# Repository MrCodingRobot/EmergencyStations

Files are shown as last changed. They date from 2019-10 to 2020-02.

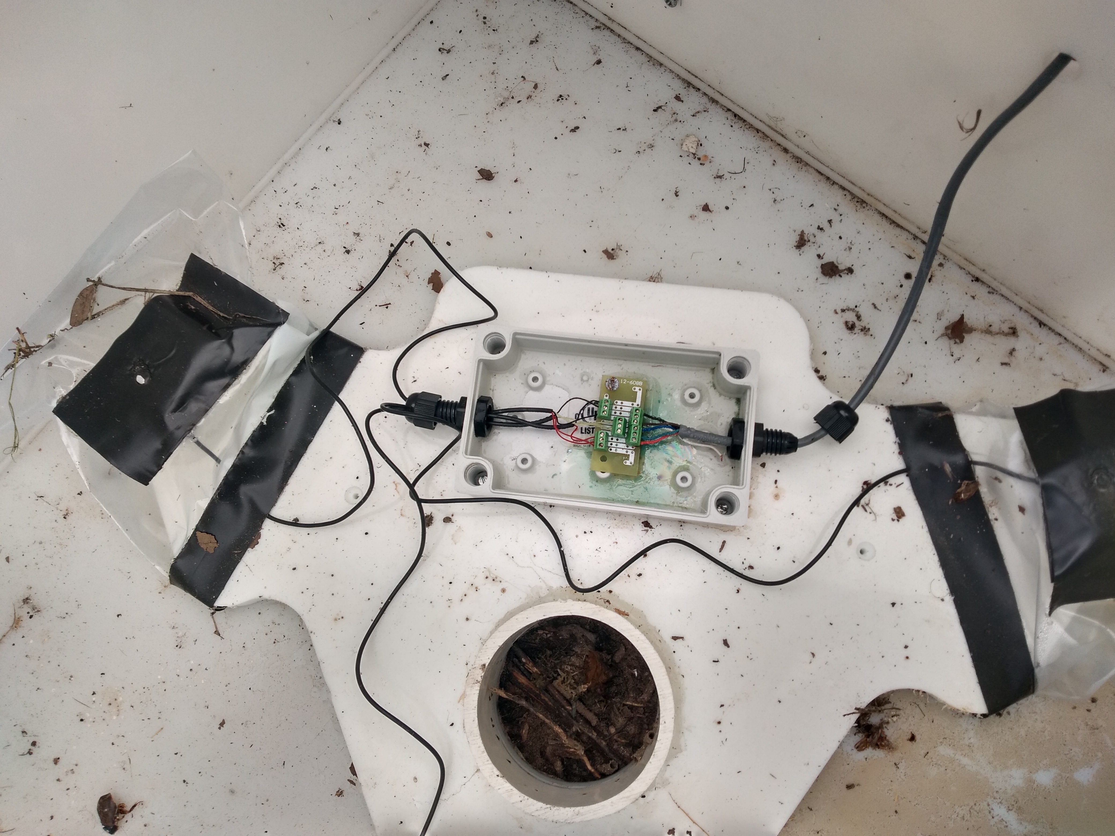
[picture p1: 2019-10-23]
Documentation/reports/trip_10_12_2019/image3.jpg

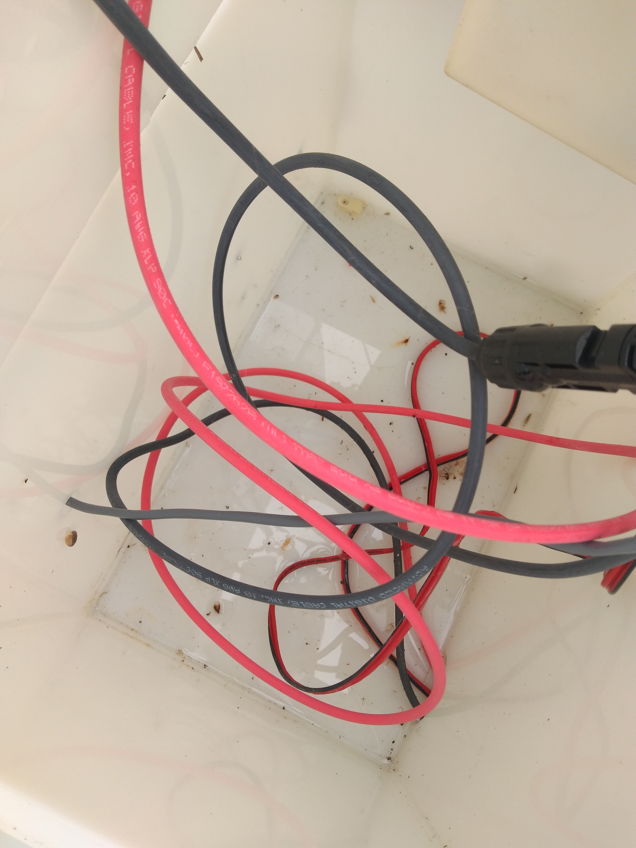
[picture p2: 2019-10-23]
Documentation/reports/trip_10_12_2019/image4.jpg

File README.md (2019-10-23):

# Emergency Stations

This project is the development of smart emergency stations. This
stations reports, via cellular data, vital inventory information that
can assist the maintance of a large collection of emergency stations.
This helps ensure that all emergency stations are stocked sufficiently
and efficiently to assure that people in need actually have supplies
when an emergency occurs.

Within this repository, the hardware, software, and additional
documentation regarding the projects development are collected.
The goal of this repository is to ensure that development progress
into this project is documentated, to make the continuation of this
project possible.

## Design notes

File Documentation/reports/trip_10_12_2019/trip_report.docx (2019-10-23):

October 12, 2019 Trip Report

Farzan A., Mehran A., Eduardo D., David (Ethan) D.

Purpose

- Implement hardware and software changes into all of the 5 phase 1 water stations.
  - Hardware
    - Placed 4x4 blocks underneath the stations to elevate the stations, making water accumulation less probable.
    - Drilled drain holes in all compartments.
    - Removed water-proof tarps (due to accumulation of bugs/snakes).
    - Improved lids for electrical boxes.
    - Implemented better water-proof connectors between weight sensors and the electrical box.
    - Implemented better weight sensor covers, from plastic bags to 3D-printed tight seals.
  - Software
    - Improved arduino and network control software.
    - Implemented station-dependent calibration to improve weight calculation.

Past Error Observations

- Phase 2 Station 6 case broke in center point due to weight. Trashed.
- Previous box connectors between weight sensors and electrical box were flooded. This can be seen in the images within the current working directory of this file. This explains why station 5 (confirmed) was not reporting correct values.
- Water accumulation in all compartment was true. This is due to a lack of drain holes.
  - Electrical boxes were compromised due to weak water seal in lids
  - Weight sensors were wet.

Problems Encountered

- Station 3 had different electrical configuration within the electrical box
  - Arduino in station 3 was powered from battery instead of solar charger.
- One of the weight sensors from station 5 was faulty, had to replace it by salvaging a sensor from broken phase 2 station 6 weight sensors. They are the same type of sensors, with the same max weight value (100 lbs).

Post-Trip Tasks

- Normalize station 3 electrical box to conform with the other electrical boxes .
- Monitor the operation of all the stations to ensure that they are working.

Post-Trip Failures

- Station 4 is not transmitting any information, need to help troubleshoot this station.
- Website is not updating google maps markers

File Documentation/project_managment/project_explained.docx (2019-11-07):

EMERGENCY STATIONS

PROJECT EXPLAINED

Version 1

Date: 11/6/2019

Document’s Purpose: To explain the innerworkings of the project to achieve the project’s vision. This is an extensive document elaborating the software and hardware of the project.

MECHANICAL HARDWARE

***

This section needs some work and the CAD files for the mechanical hardware is missing!

***

ELECTRICAL HARDWARE

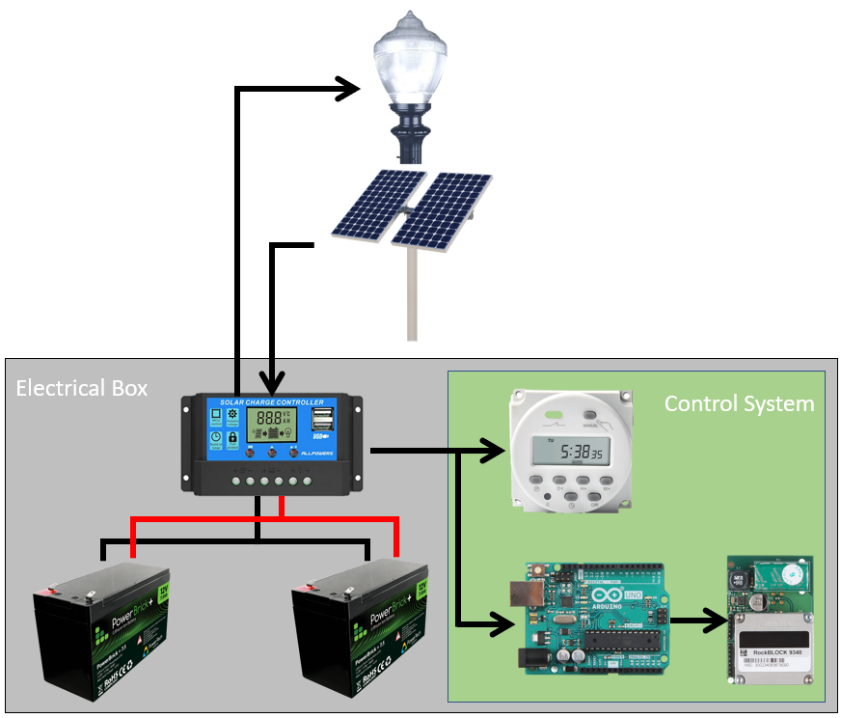
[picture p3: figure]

Figure 2.1: Electrical Hardware Diagram

This section deals with the electrical hardware of the system, consisting of the solar panels, solar charger controller, rechargeable 12V Lithium batteries, and the control system. The control system is composed of digital clock switch for the pole’s light, a microcontroller (Arduino) and the communication module (RockBLOCK).

The power obtained from the solar panel is processed and handle by the solar charger controller to properly charge the 12V batteries. Then the solar charger controller has a USB port that is used to run the Arduino and the RockBLOCK. Whenever the solar panel is not outputting enough voltage to power the solar charger, the voltage of the batteries ensure that the solar charger controller is powered and supplying power to the control systems.

SOFTWARE

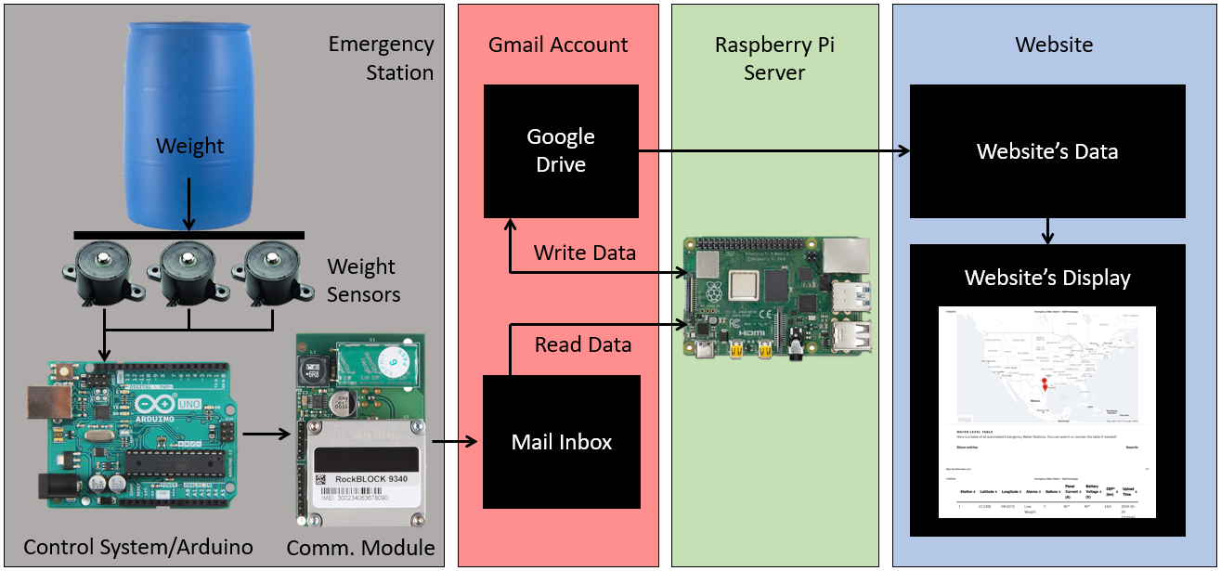
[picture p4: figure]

Figure 3.1: Software Subsystem Diagram

The software subsystem of the project is composed of two main components: the emergency station software within the Arduino, and the Raspberry Pi Server. The weight within a barrel is recorded by three weight sensors. The weight values are summed and converted to a value in pounds (lbs.). Weight values are recorded every 90 minutes for a total of eight times. One cycle of data collection is 12 hours. Afterwards, these values are transmitted by the Communication Module (RockBLOCK) that is connected to the Arduino.

When the Communication Module transmits data, it is sent as an email where the subject contains the GPS location of the module and the weight data recorded by the Arduino. The Raspberry Pi Server is routinely checking for new emails from the ESs. If a new email is detected, the weight data within the new email is read, recorded, and saved to a master excel file within the gmail’s google drive. Additionally, the Raspberry Pi generates other excel files that update the GPS locations within the Google Maps plugin and the most up to date ESs’ inventory values within a Table plugin. These plugins are supplied by WordPress, which is the platform used to operate the website.

The latest 100 points from the data points of the ES is used to plot the changing weight and sensor values. This helps diagnose and troubleshoot possible problems for individual ES.

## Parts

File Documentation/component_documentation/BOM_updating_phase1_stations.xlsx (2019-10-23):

Quantity | Part | Tools Needed
4 | Water Station Lid | Drill
12 | Force Sensor Cover | 1in drill bit
16 | 3/8x2.5in lag screws and washers | 3/8in drill bit
8 | 2ft 4x4 boards | 1/4in drill bit
4 | 6-pin waterproof connectors | soldering iron
1 | heat shrink tubing | socket wrench (7/16in or 1/2in)
1 | gorillaz table

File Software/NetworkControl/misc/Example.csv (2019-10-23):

id | map_id | address | description | pic | link | lat | lng | icon | anim | title | infoopen | category | approved | retina | type | did | other_data
6435 | 81 | 39.90498,116.427217 |  |  |  | 39.90498 | 116.427217 |  | 0 | Beijing Railway Station | 0 | 0 | 1 | 0 | 0
6436 | 81 | 39.894834,116.32111 |  |  |  | 39.894834 | 116.32111 |  | 0 | Beijing West | 0 | 0 | 1 | 0 | 0
6437 | 81 | 32.086727,118.796834 |  |  |  | 32.086727 | 118.796834 |  | 0 | Nanjing Railway Station | 0 | 0 | 1 | 0 | 0
6438 | 81 | 31.2508246,121.4506144 |  |  |  | 31.250825 | 121.450614 |  | 0 | Shanghai Railway Station | 0 | 0 | 1 | 0 | 0
6439 | 81 | 24.636169,118.074064 |  |  |  | 24.636169 | 118.074064 |  | 0 | Xiamen North Railway Station | 0 | 0 | 1 | 0 | 0
6440 | 81 | 22.989053,113.269698 |  |  |  | 22.989053 | 113.269698 |  | 0 | Guangzhou South | 0 | 0 | 1 | 0 | 0
6441 | 81 | 30.6311561,104.1390591 |  |  |  | 30.631156 | 104.139059 |  | 0 | &#x6210;&#x90FD;&#x4E1C; | 0 | 0 | 1 | 0 | 0 |  | a:1:{i:0;s:1:"0";}
6442 | 81 | 28.146783,113.06508 |  |  |  | 28.146783 | 113.06508 |  | 0 | &#x957F;&#x6C99;&#x5357; | 0 | 0 | 1 | 0 | 0 |  | a:1:{i:0;s:1:"0";}
6443 | 81 | 30.696822,104.073374 |  |  |  | 30.696822 | 104.073374 |  | 0 | Chengdu Railway Station | 0 | 0 | 1 | 0 | 0
6444 | 81 | 29.549747,106.547669 |  |  |  | 29.549747 | 106.547669 |  | 0 | Chongqing Railway Station | 0 | 0 | 1 | 0 | 0

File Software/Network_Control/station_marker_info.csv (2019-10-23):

id | map_id | address | description | pic | link | lat | lng | icon | anim | title | infoopen | category | approved | retina | type | did | other_data
1 | 81 | 29.4434,-98.5267 |  |  |  | 29.4434 | -98.5267 |  | 0 | Station 1 | 0 | 0 | 1 | 0 | 0
24 | 81 | 27.2013,-98.1072 |  |  |  | 27.2013 | -98.1072 |  | 0 | Stations 2, and 4 | 0 | 0 | 1 | 0 | 0
3 | 81 | 27.2334,-98.1072 |  |  |  | 27.2334 | -98.1072 |  | 0 | Station 3 | 0 | 0 | 1 | 0 | 0
5 | 81 | 27.1990,-98.1472 |  |  |  | 27.1990 | -98.1472 |  | 0 | Station 5 | 0 | 0 | 1 | 0 | 0
6 | 81 | 27.0354,-98.1757 |  |  |  | 27.0354 | -98.1757 |  | 0 | Station 6 | 0 | 0 | 1 | 0 | 0

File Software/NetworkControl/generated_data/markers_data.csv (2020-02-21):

id | map_id | address | description | pic | link | lat | lng | icon | anim | title | infoopen | category | approved | retina | type | did | other_data
1 | 81 | 26.9893, -98.1301 |  |  |  | 26.9893 | -98.1301 |  | 0 | Station 1 | 0 | 0 | 1 | 0 | 0
2 | 81 | 26.5789, -99.0332 |  |  |  | 26.5789 | -99.0332 |  | 0 | Station 2 | 0 | 0 | 1 | 0 | 0
3 | 81 | 27.2311, -98.1472 |  |  |  | 27.2311 | -98.1472 |  | 0 | Station 3 | 0 | 0 | 1 | 0 | 0
4 | 81 | 27.199, -98.1472 |  |  |  | 27.199 | -98.1472 |  | 0 | Station 4 | 0 | 0 | 1 | 0 | 0
5 | 81 | 26.987, -98.17 |  |  |  | 26.987 | -98.17 |  | 0 | Station 5 | 0 | 0 | 1 | 0 | 0

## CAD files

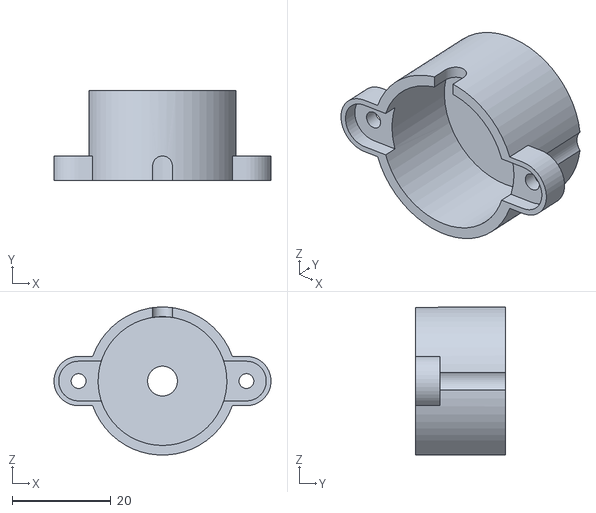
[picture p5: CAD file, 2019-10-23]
Hardware/force sensor cover.STL
44.0 x 18.3 x 30.0

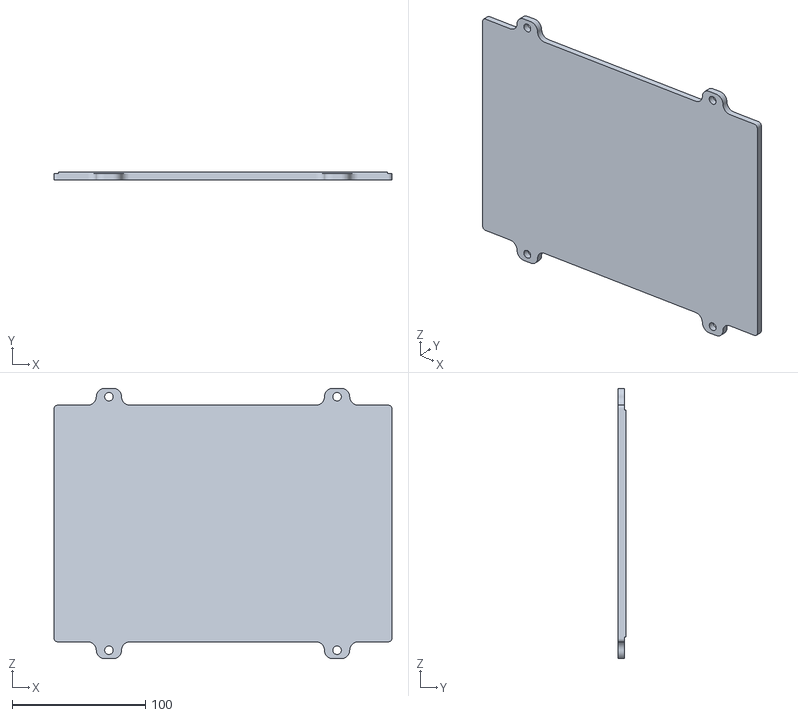
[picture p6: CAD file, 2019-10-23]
Hardware/water station lid.STL
254.0 x 6.03 x 203.2

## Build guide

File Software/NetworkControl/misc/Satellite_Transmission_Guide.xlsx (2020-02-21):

 | Stored Data
Index | Phase 1 | Phase 2
0 | Station # | Station #
1 | Alarm | Alarm
2 | Sensor1 1 | Weight 1
3 | Sensor2 1 | Current 1
4 | Sensor3 1 | Voltage 1
5 | Reference 1 | Weight 2
6 | Weight 1 | Current 2
7 | Sensor1 2 | Voltage 2
8 | Sensor2 2 | Weight 3
9 | Sensor3 2 | Current 3
10 | Reference 2 | Voltage 3
11 | Weight 2 | Weight 4
12 | Sensor1 3 | Current 4
13 | Sensor2 3 | Voltage 4
14 | Sensor3 3 | Weight 5
15 | Reference 3 | Current 5
16 | Weight 3 | Voltage 5
17 | Sensor1 4 | Weight 6
18 | Sensor2 4 | Current 6
19 | Sensor3 4 | Voltage 6
20 | Reference 4 | Weight 7
21 | Weight 4 | Current 7
22 | Sensor1 5 | Voltage 7
23 | Sensor2 5 | Weight 8
24 | Sensor3 5 | Current 8
25 | Reference 5 | Voltage 8
26 | Weight 5 | Weight 9
27 | Sensor1 6 | Current 9
28 | Sensor2 6 | Voltage 9
29 | Sensor3 6 | Weight 10
30 | Reference 6 | Current 10
31 | Weight 6 | Voltage 10
32 | Sensor1 7 | Weight 11
33 | Sensor2 7 | Current 11
34 | Sensor3 7 | Voltage 11
35 | Reference 7 | Weight 12
36 | Weight 7 | Current 12
37 | Sensor1 8 | Voltage 12
38 | Sensor2 8 | Weight 13
39 | Sensor3 8 | Current 13
40 | Reference 8 | Voltage 13
41 | Weight 8 | Weight 14
42 | EMPTY | Current 14
43 | EMPTY | Voltage 14
44 | EMPTY | Current Index*
45 | Present Weight | Present Weight
46 | EMPTY | Present Current
47 | EMPTY | Present Voltage
 |  | *Current Index is the index where the current readings (besides the "present" readings) are held.
 |  | Readings from the past 12 hours are interpretted by reading the values at the current index and
 |  | working backwards, wrapping around as needed.

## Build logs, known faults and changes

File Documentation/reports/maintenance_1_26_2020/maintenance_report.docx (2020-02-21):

Maintenance Report

01/26/2020 – 8:20 PM

Eduardo D.

Note: The original larger-size higher-quality JPGs of the stations’ historical data is available within this file’s current working directory.

Station 1 (Phase 1) - 300234067638620@rockblock.rock7.com

Status: Deployed, Idle (Non-functioning properly)

Last Email Received Datetime: 01/08/2020 – 10:31 PM (Website values agree)

Last Weight Value: 6 gallons

Historical Data:

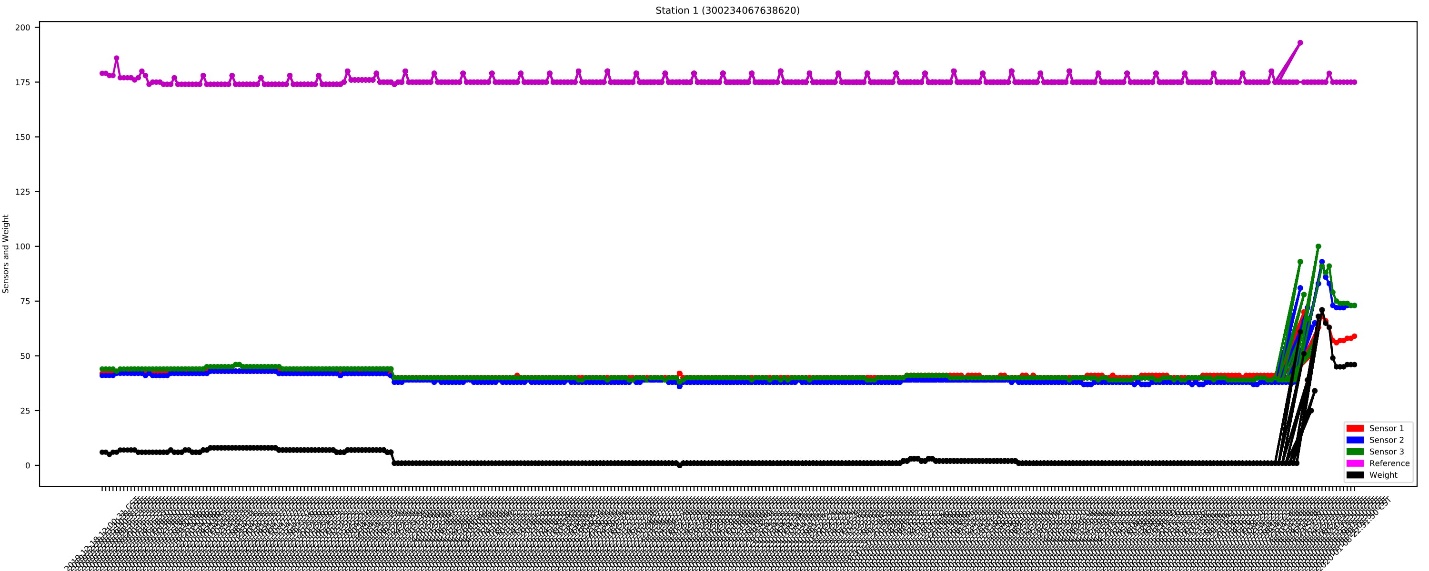
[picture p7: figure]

Diagnosis:

The high concentration of data points at the end of this plot implies that a reset was attempted. The reset is recognized to have occurred on late 1/07/2020. After the reset, there is a small amount of stability for the sensor and weight values, implying that the station was functional after the reset. However, this station has stopped transmitting the information. The most likely cause of this discontinued of service can be the following (of decreasing likeability:

- Software Fault after automatic reset (the case was not tested during development)
- Wiring Disconnection during water station deployment
- Faulty redeployment
- RockBLOCK communication failure
- Arduino Long Operation failure (memory issues ?)

Station 2 (Phase 1) - 300234067639570@rockblock.rock7.com

Status: Deployed, Idle (Non-functioning properly)

Last Email Received Datetime: 01/08/2020 – 7:58 PM (Website values agree)

Last Weight Value: 12 gallons

Historical Data:

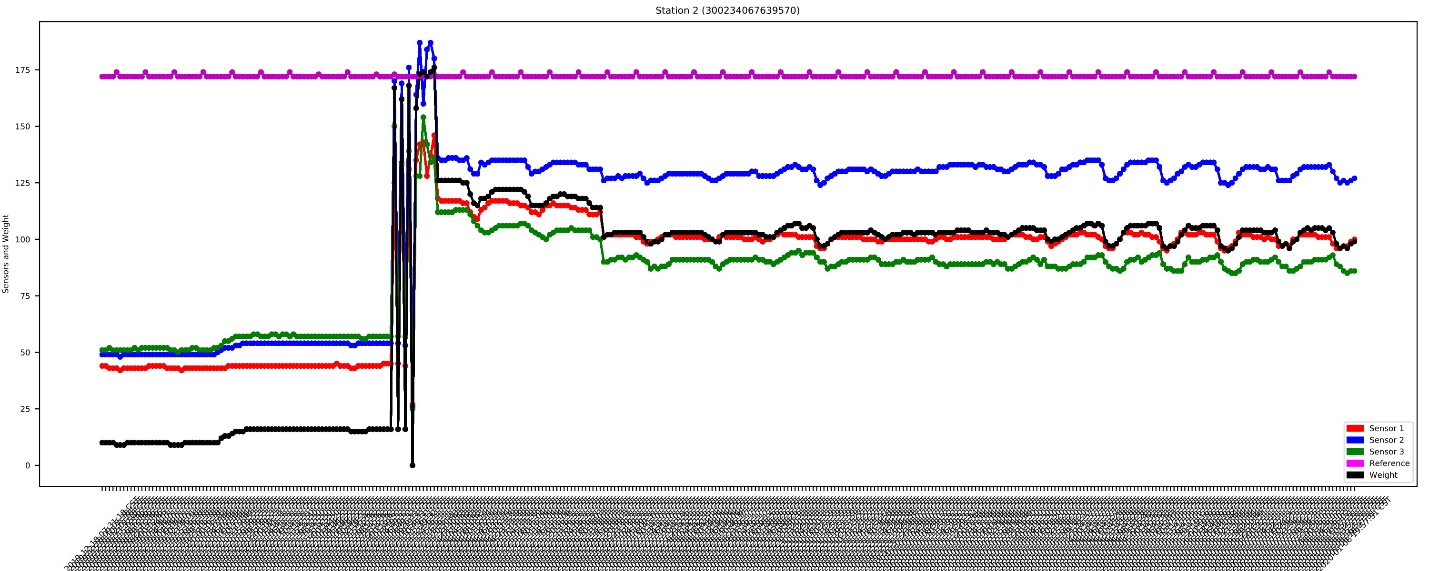
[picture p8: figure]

Diagnosis:

This station was deployed on 12/23/2019 (based on what our data says, not what the user says), which is then placed where the graph spikes up in value. This is mostly due to the changing value of the weight sensors during setup. Then the station stagnates for a period of time, mostly at around 100 lbs (≈12 gallons) for the weight. This agrees with the most up-to-date value in the southtexashrc.com website, it reported 12 gallons. This water station is much more difficult to diagnosis as the station just suddenly stopped transmitting the information. The fact that it stopped transmitting information the same day Station 1 failed implies that an external force is the cause of the problem.

Station 3 (Phase 1) - 300234067431270@rockblock.rock7.com

Status: Unknown, Idle (Unknown – Possibly not powered)

Last Email Received Datetime: 09/12/20219 – 7:29 PM

Last Weight Value: 2 gallons (Website values agree)

Historical Data:

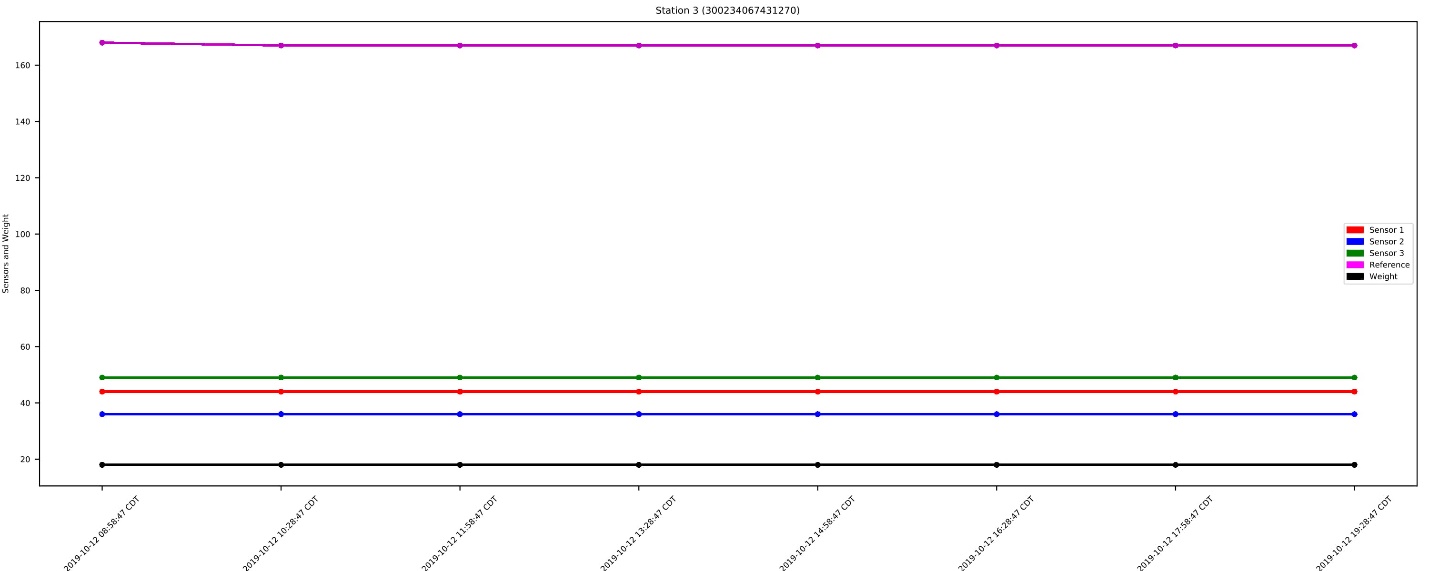
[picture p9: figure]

Diagnosis:

The trip to change Phase 1 stations occurred on October 12, 2019. During this trip, we realized that station 3 had a different electrical layout where the Arduino microcontroller was connected to the batteries through its 9V input port instead of being connected to the solar charger via a USB connector. We tried to make this station conform with the other water stations' circuit layout. However, we realized that the USB port of the solar charger in station 3 was faulty and could not be used. The electrical box was returned to on-site personnel. We are waiting for them to place the electrical box to its designated compartment and initiate the station's service.

Station 4 (Phase 1) - 300234067638500@rockblock.rock7.com

Status: Unknown, Idle (Definitely Non-functioning properly)

Last Email Received Datetime: 09/12/2019 – 6:53 PM

Last Weight Value: 3 gallons (Website values agree)

Historical Data:

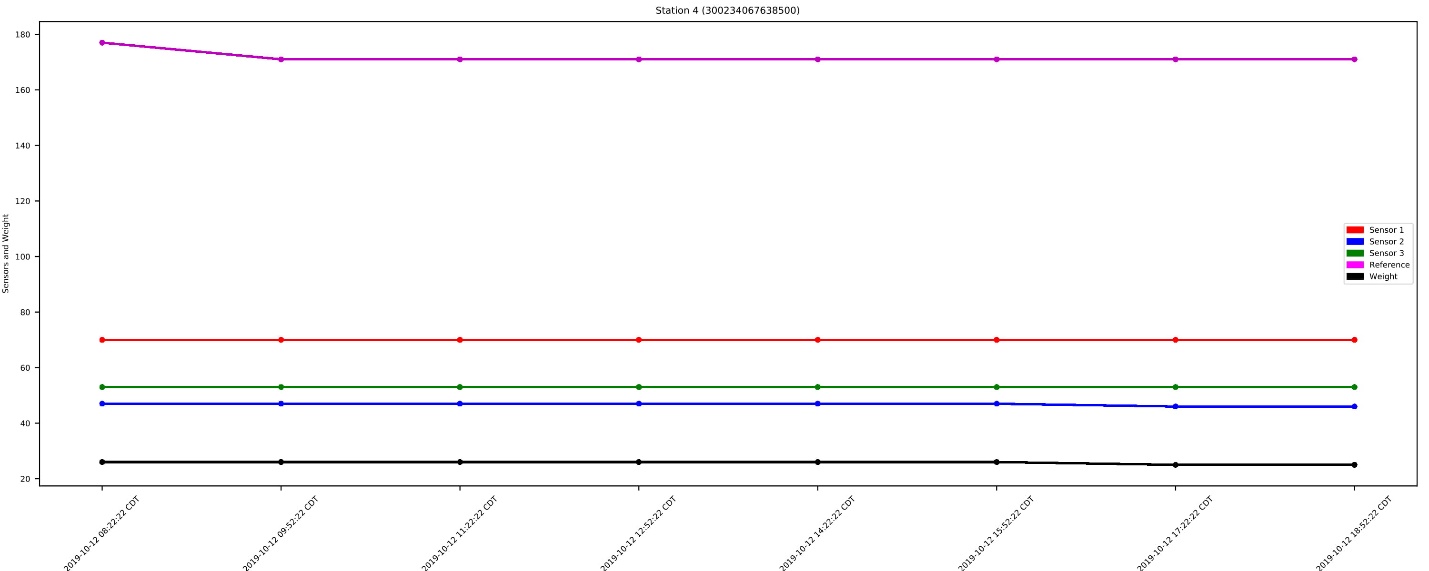
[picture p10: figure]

Diagnosis:

During the 09/12/19 trip, station 4 was modified, calibrated, setup, and confirm to have transmitted its first email. Once the engineering team returned to San Antonio, station 4 stopped transmitting the information. The cause remains unknown. We have not received any additional information regarding the station; therefore, communication with on-site personnel is needed to properly diagnose.

Possible Causes:

- Faulty Setup
- Faulty Calibration
- ???

Station 5 (Phase 1) - 300234067638200@rockblock.rock7.com

Status: Deployed, Idle (Non-functioning properly)

Last Email Received Datetime: 01/08/2020 – 5:02 PM

Last Weight Value: 6 gallons (Website values agree)

Historical Data:

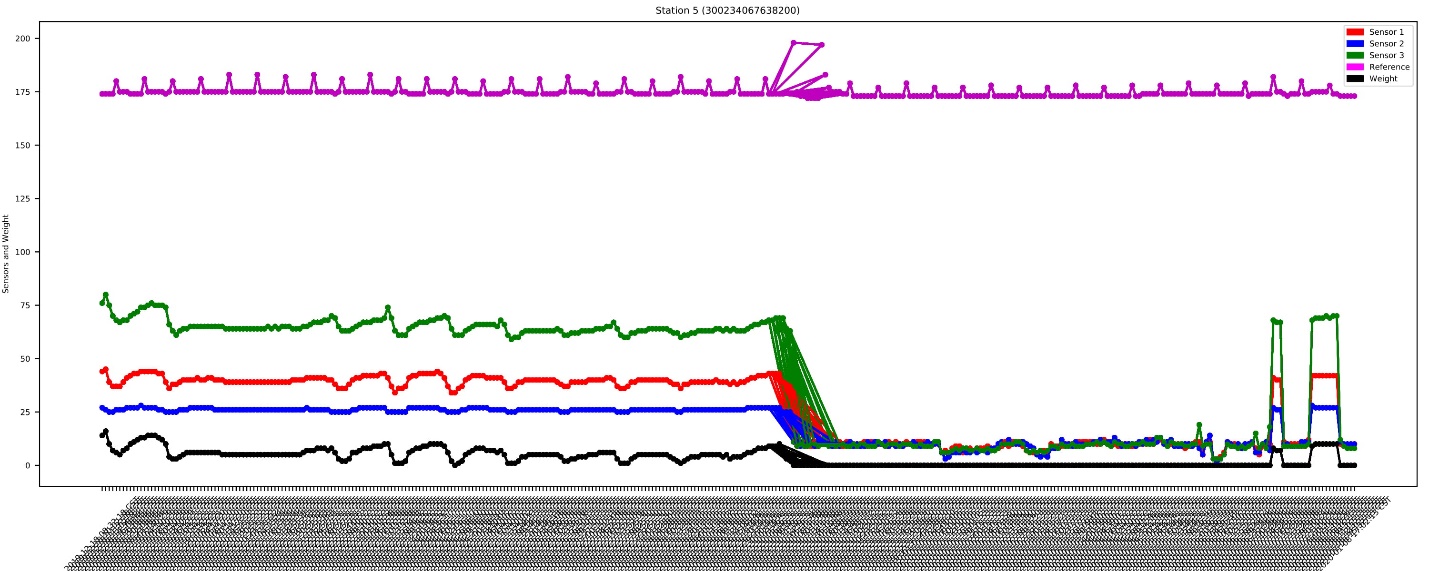
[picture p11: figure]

Diagnosis:

When the weight of the station is 0, or just very low, it implies that the barrel was removed. We can see in the far right of the plot that the barrel was repetitively removed and replaced. The transmission of data ended on 01/08/2020, which is also the same time as stations 1 and 2 failed, implying that the problem is linked together and related to a shared external force.

Station 6 (Phase 2) - 300234067929930@rockblock.rock7.com

Status: Dead

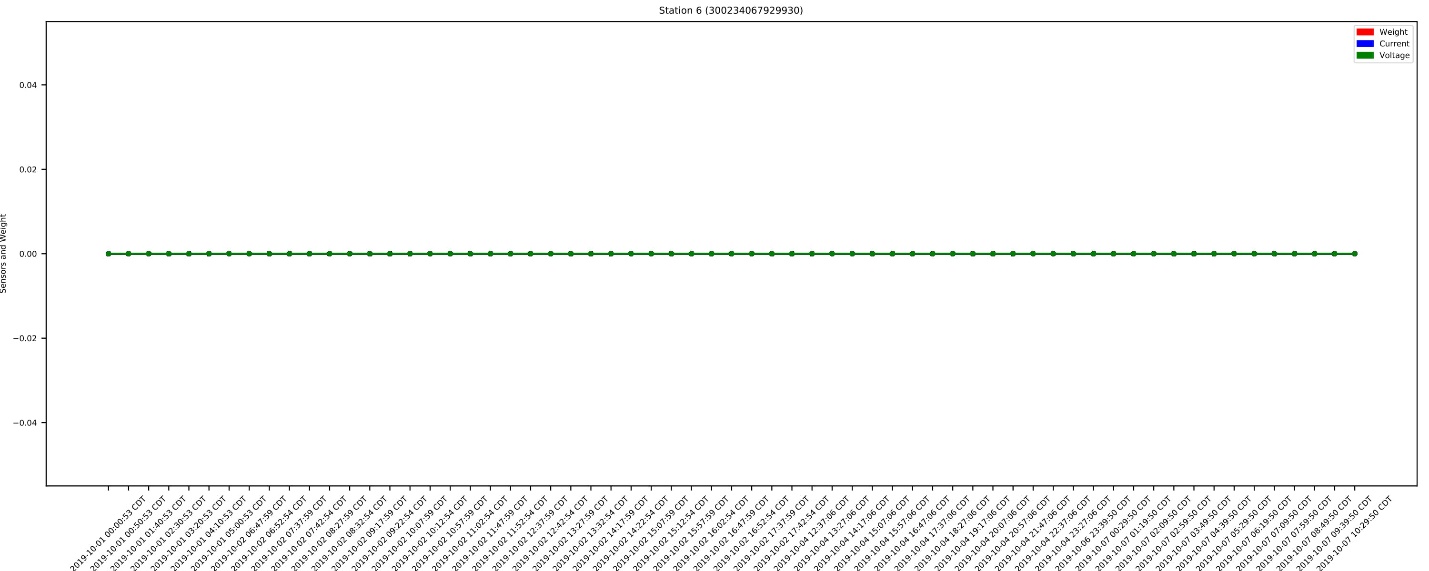
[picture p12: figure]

Diagnosis:

Discontinued station – the station was broken and tossed in the trash.

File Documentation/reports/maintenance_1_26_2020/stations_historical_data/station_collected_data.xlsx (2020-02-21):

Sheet: Station 1 (300234067638620)
Time | Sensor 1 | Sensor 2 | Sensor 3 | Reference | Weight
2019-11-15 01:08:10 CST | 43 | 42 | 44 | 183 | 7
2019-11-15 02:38:10 CST | 43 | 42 | 44 | 177 | 7
2019-11-15 04:08:10 CST | 43 | 42 | 44 | 177 | 7
2019-11-15 05:38:10 CST | 43 | 42 | 44 | 177 | 7
2019-11-15 07:08:10 CST | 43 | 42 | 44 | 177 | 7
2019-11-15 08:38:10 CST | 43 | 42 | 44 | 177 | 7
2019-11-15 10:08:10 CST | 42 | 42 | 44 | 177 | 6
2019-11-15 11:38:10 CST | 43 | 42 | 43 | 176 | 6
2019-11-15 13:12:18 CST | 43 | 41 | 44 | 182 | 6
2019-11-15 14:42:18 CST | 42 | 41 | 44 | 176 | 6
2019-11-15 16:12:18 CST | 43 | 42 | 44 | 176 | 7
2019-11-15 17:42:18 CST | 43 | 42 | 44 | 177 | 7
2019-11-15 19:12:18 CST | 43 | 42 | 44 | 177 | 7
2019-11-15 20:42:18 CST | 43 | 42 | 44 | 177 | 7
2019-11-15 22:12:18 CST | 43 | 42 | 44 | 177 | 7
2019-11-15 23:42:18 CST | 43 | 42 | 44 | 177 | 7
2019-11-16 01:15:27 CST | 43 | 42 | 44 | 182 | 7
2019-11-16 02:45:27 CST | 43 | 42 | 44 | 177 | 7
2019-11-16 04:15:27 CST | 43 | 42 | 44 | 177 | 7
2019-11-16 05:45:27 CST | 43 | 42 | 44 | 177 | 7
2019-11-16 07:15:27 CST | 42 | 42 | 44 | 177 | 6
2019-11-16 08:45:27 CST | 42 | 42 | 44 | 177 | 6
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

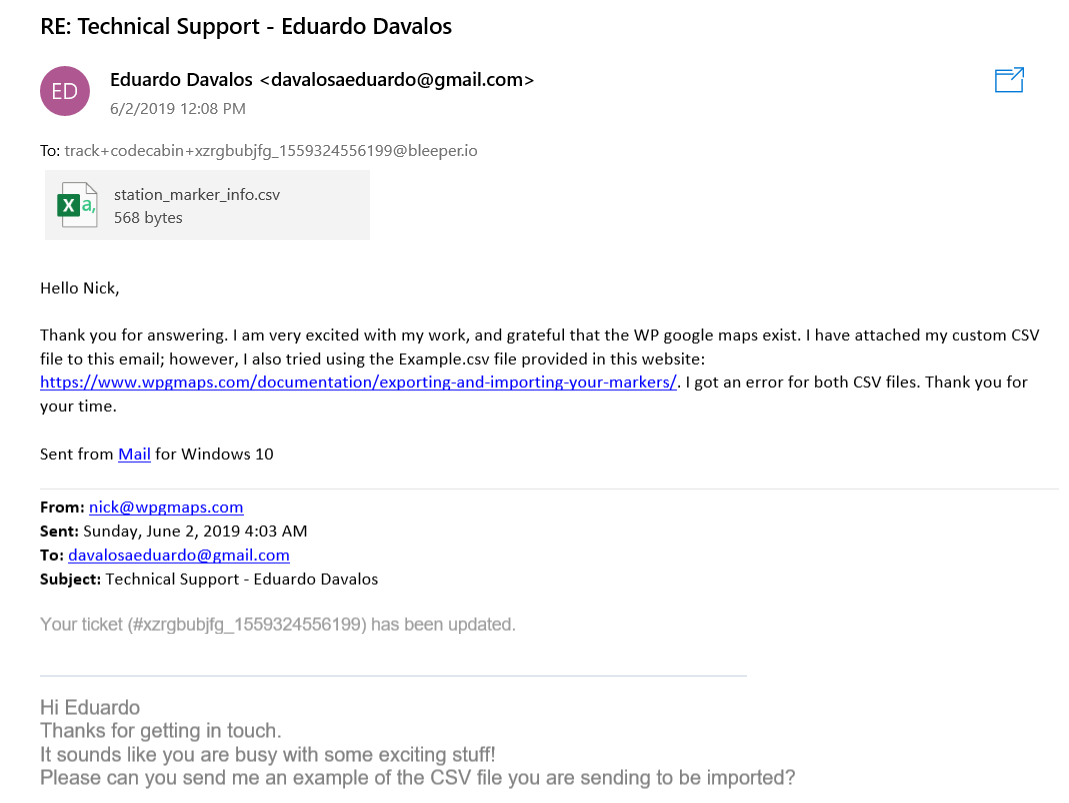
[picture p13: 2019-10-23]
Software/NetworkControl/misc/email_issues.png

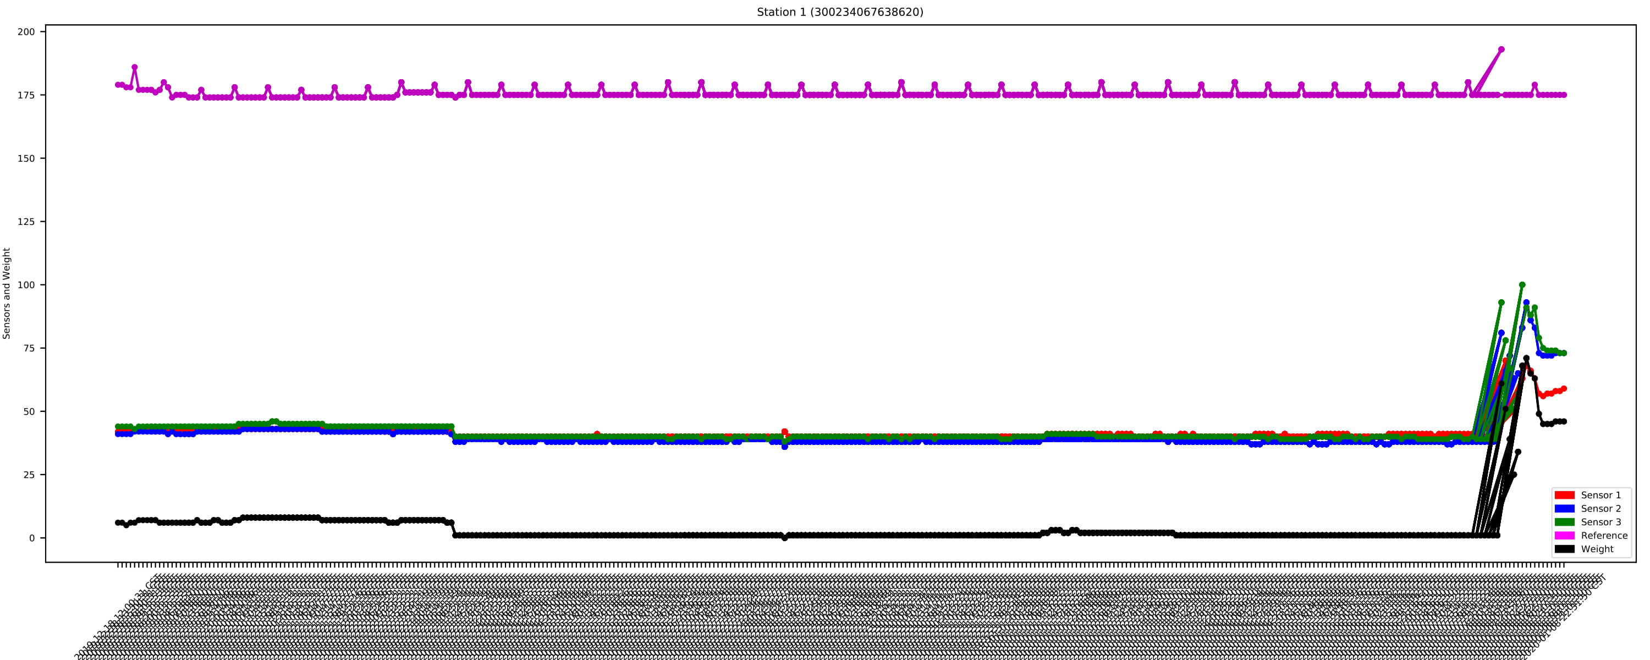
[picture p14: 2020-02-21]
Documentation/reports/maintenance_1_26_2020/stations_historical_data/water_level_charts-1-1.jpg

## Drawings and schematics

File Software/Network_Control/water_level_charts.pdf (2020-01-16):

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

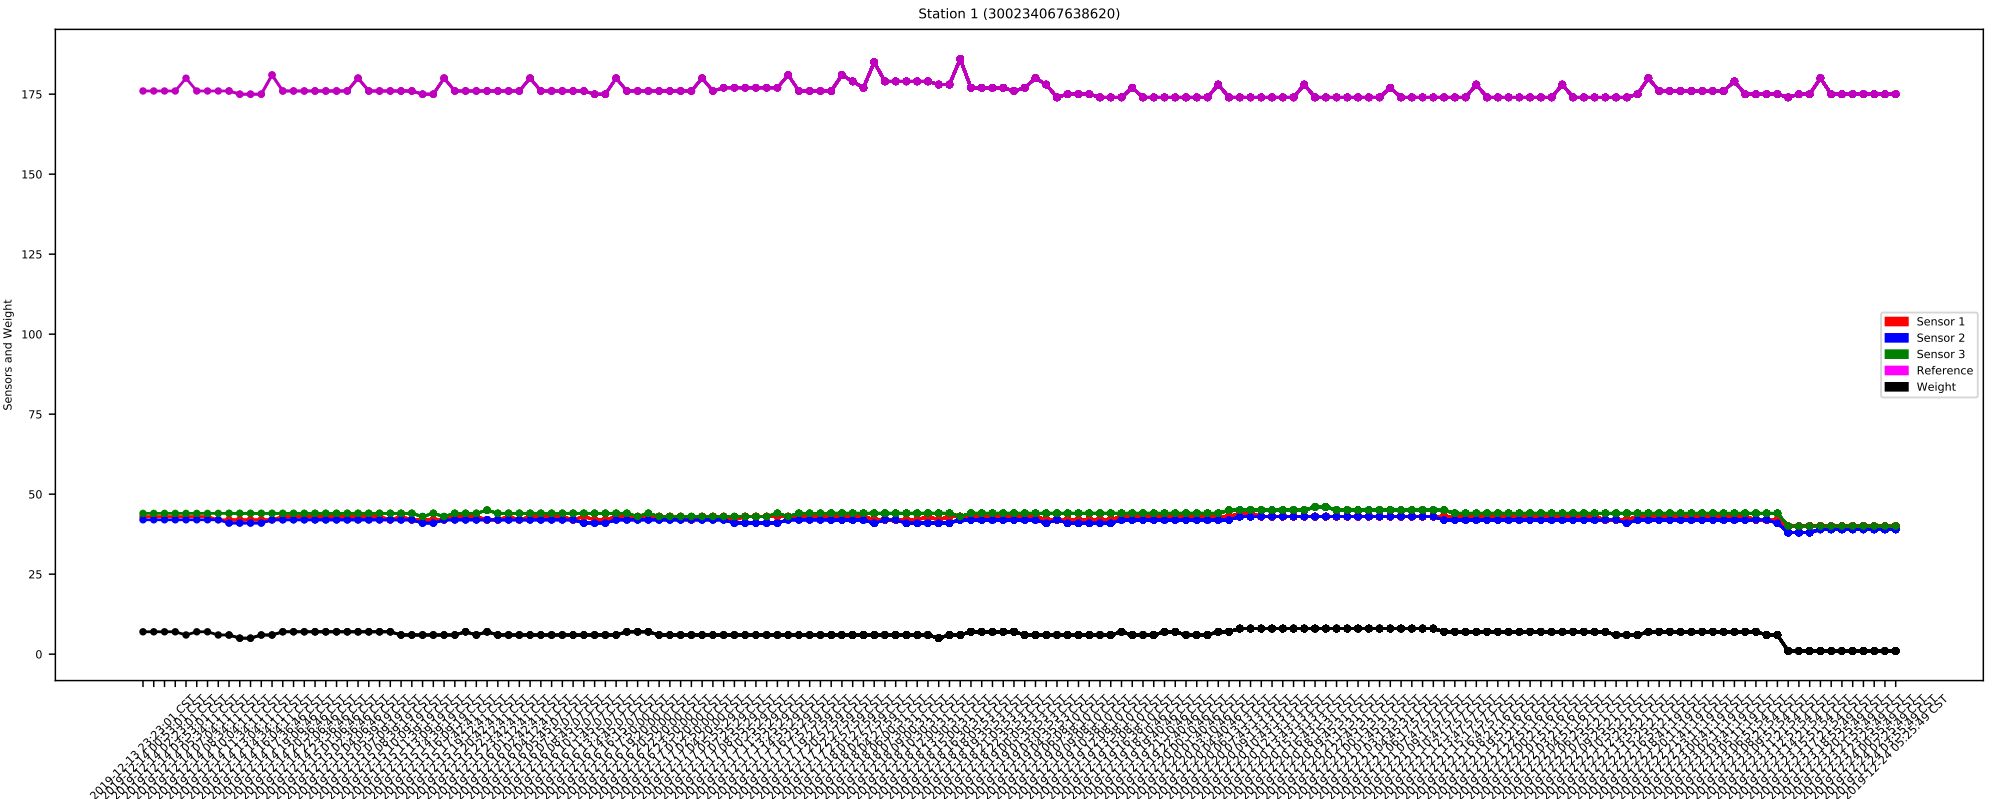
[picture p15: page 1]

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

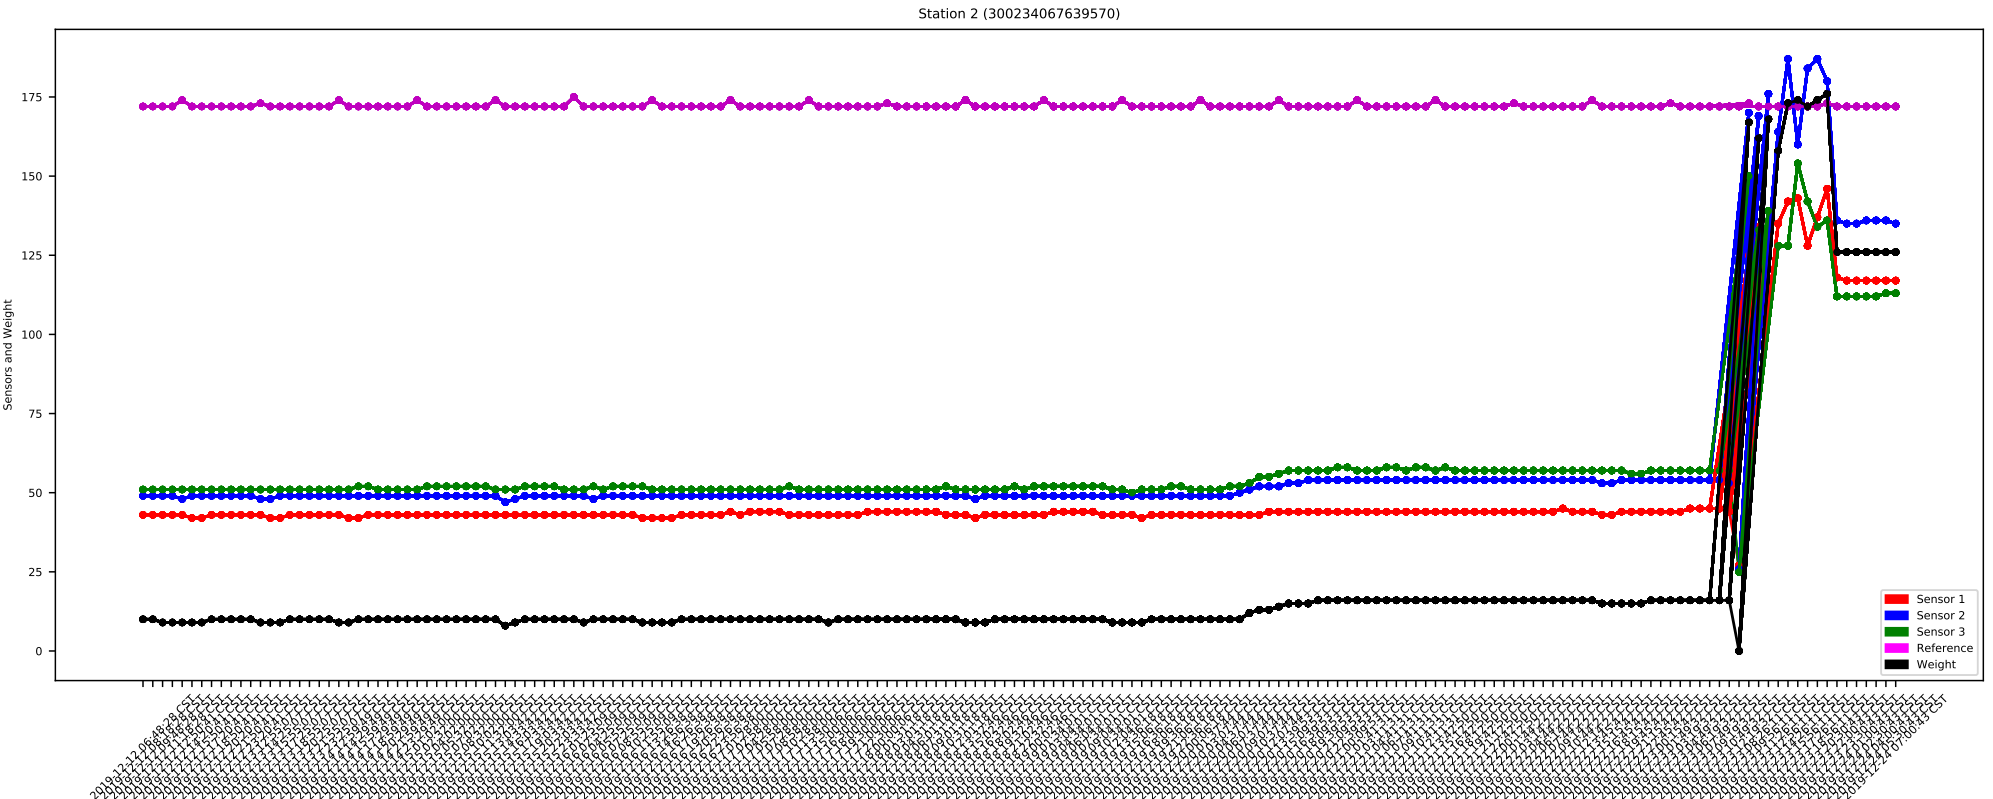
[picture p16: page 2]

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

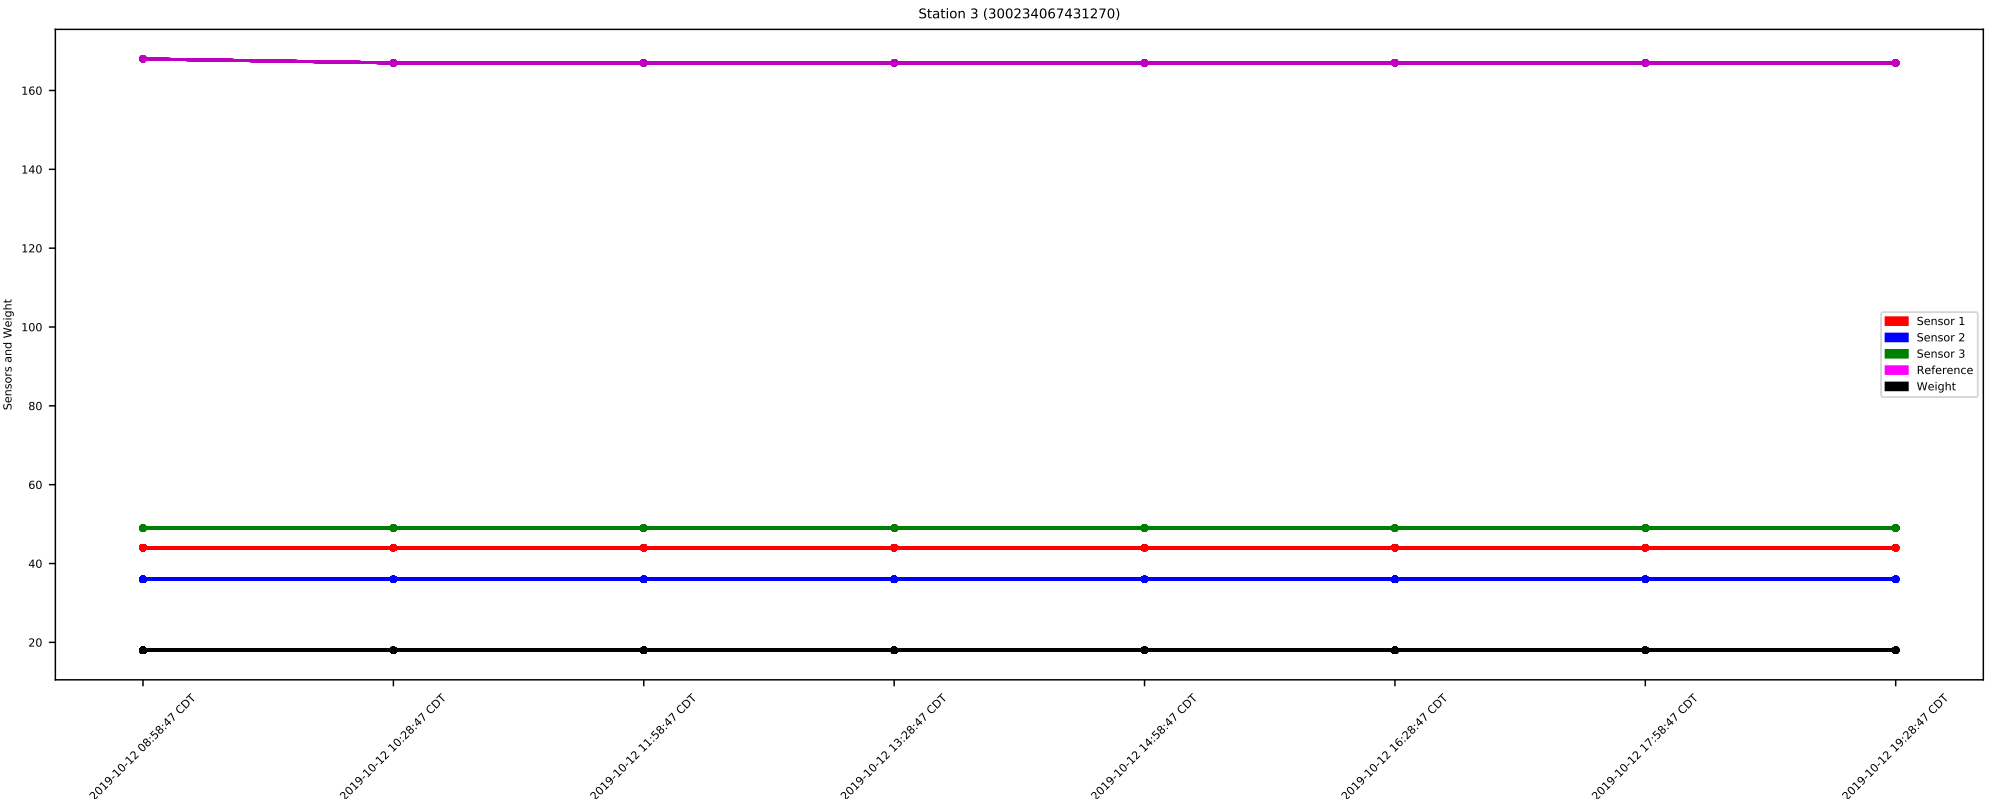
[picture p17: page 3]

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

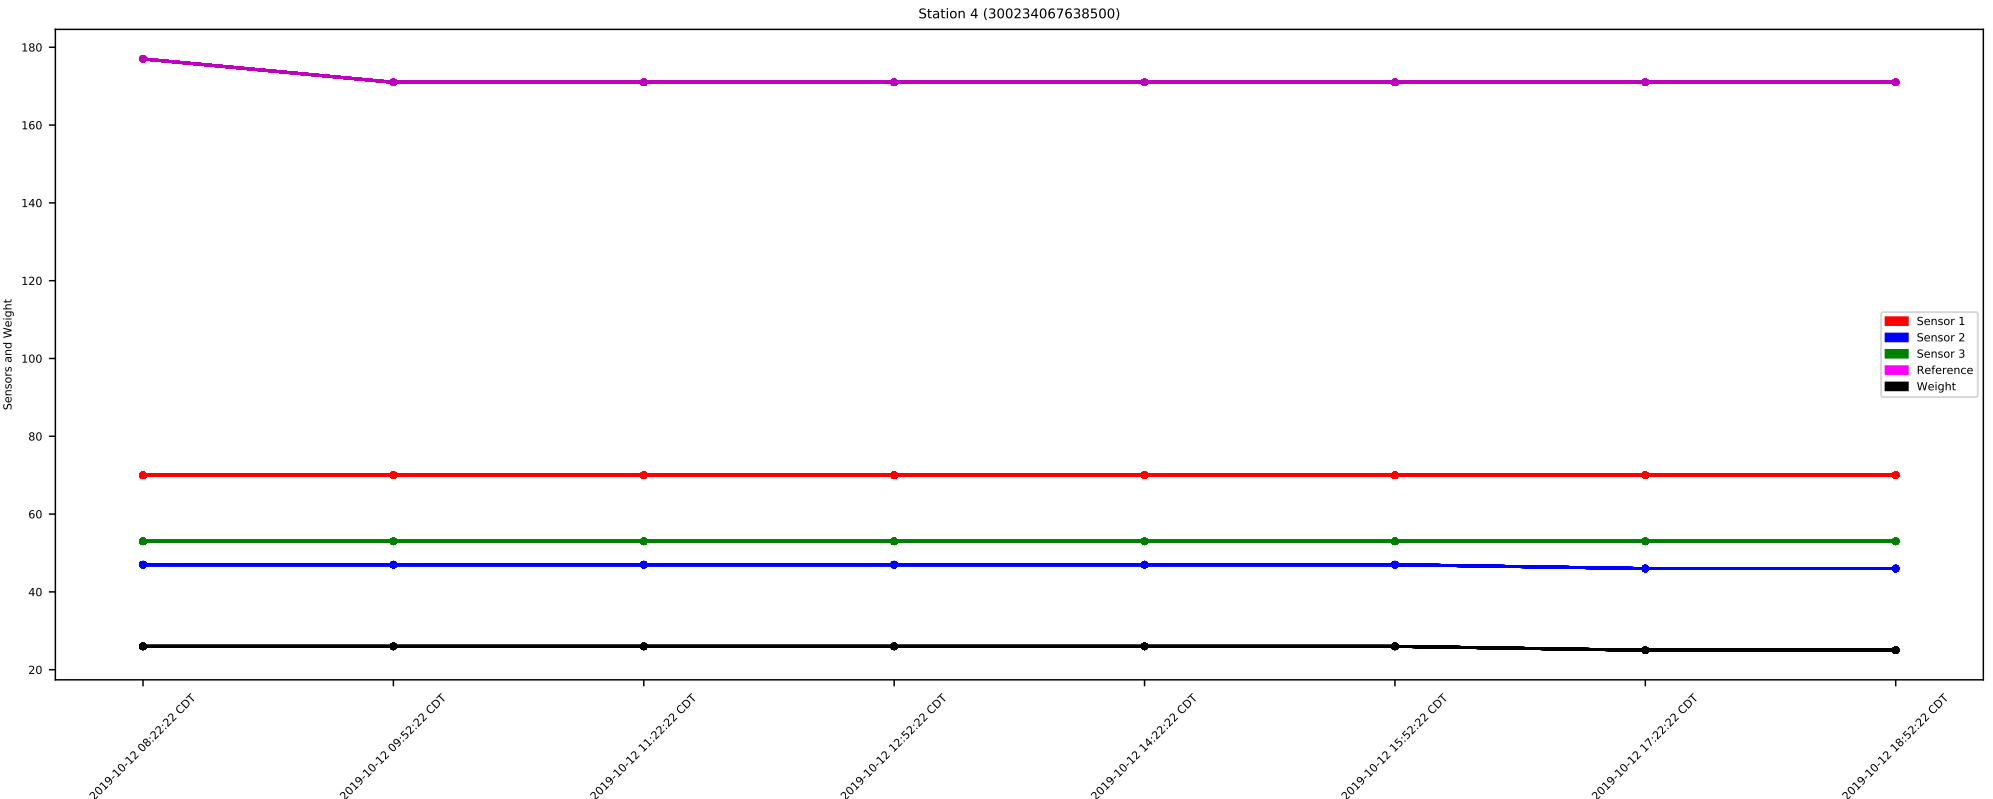
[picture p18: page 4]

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

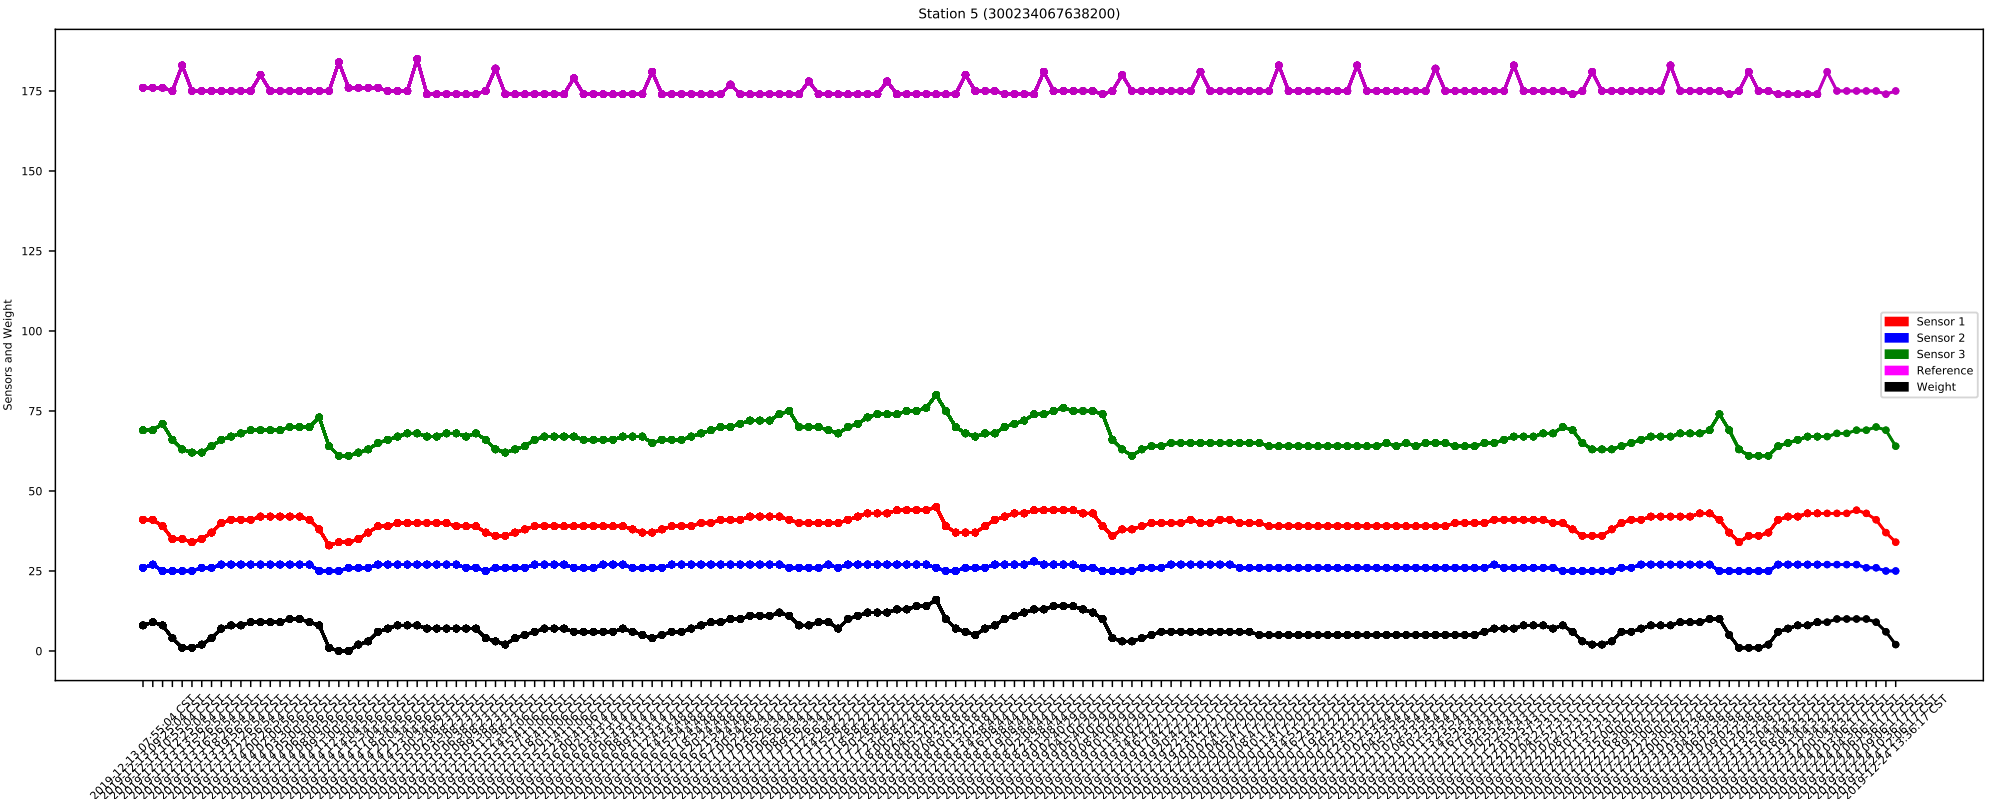
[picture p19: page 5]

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

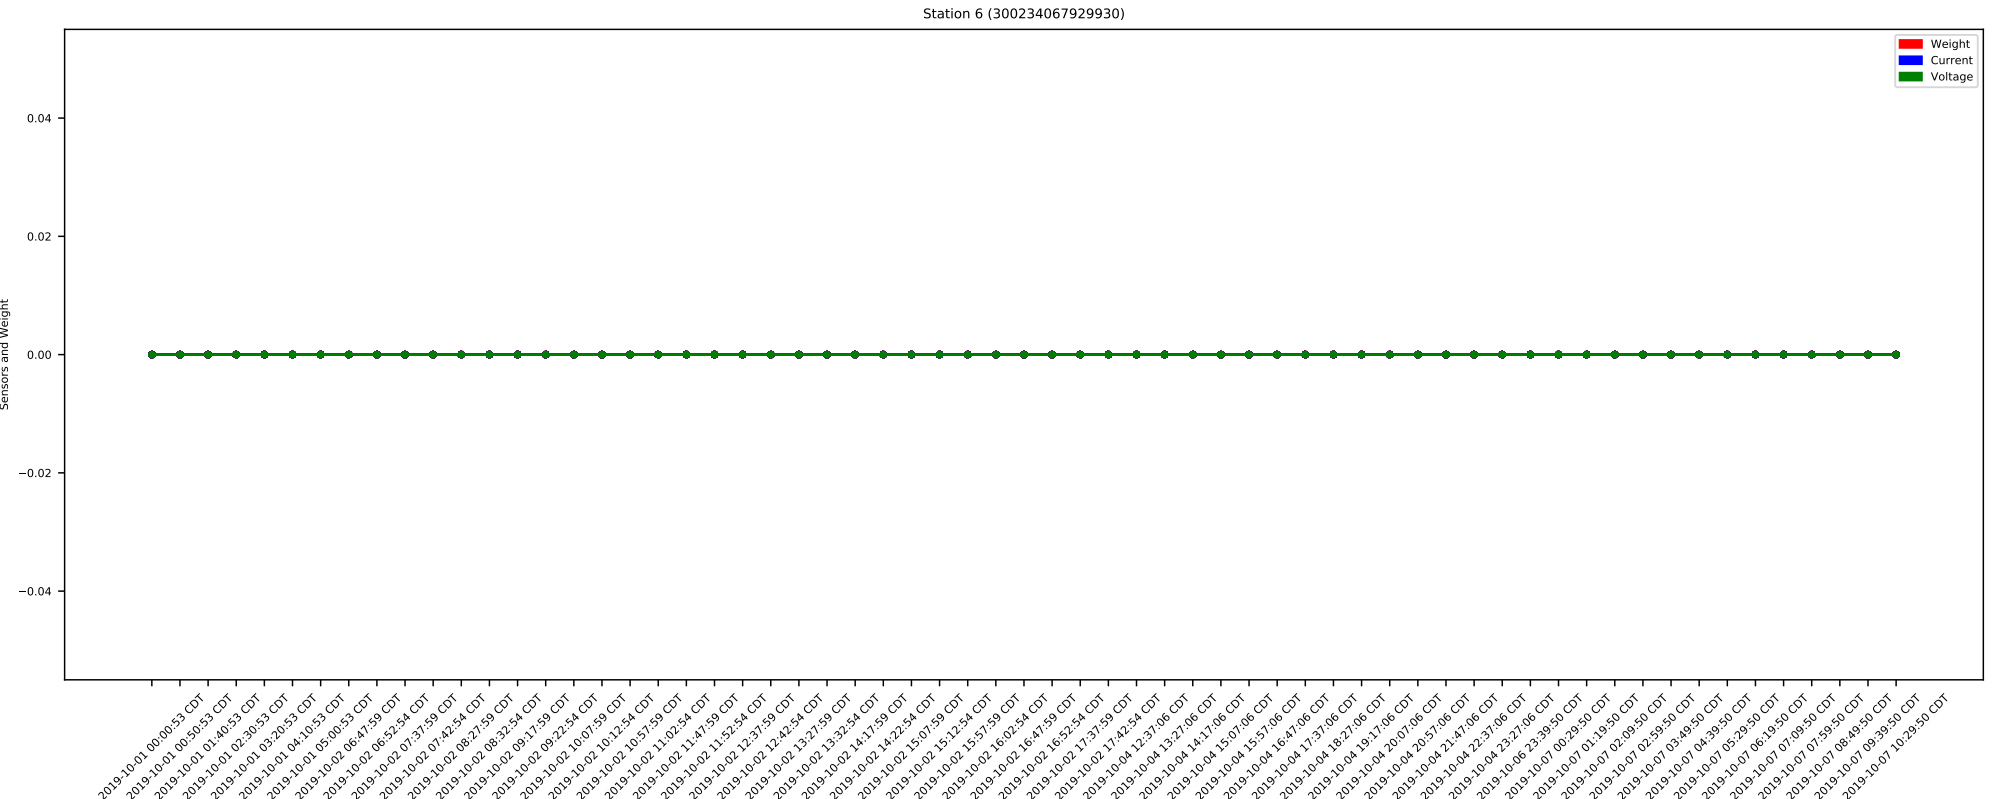
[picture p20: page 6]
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

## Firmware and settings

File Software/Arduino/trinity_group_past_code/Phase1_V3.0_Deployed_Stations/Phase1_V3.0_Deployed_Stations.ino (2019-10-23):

// V3.0 of Deployed Stations Code for Trinity Water Stations Project
// Authors: Nathan Richter
// Based on V2.2 of Deployed Stations Code for Trinity Water Stations Project by. Brady Burns,Brian Guenther, and Zach
// Last Update 5/27/2019
// Its purpose is to read 3 weight sensors, convert it to weight and then send this via satellite every twelve hours.
/* Requirements:
 * Irridium SBD Library installed, Version of Arduino must be 1.6.21, Arduino MEGA, RockBLOCK V2.c, 4 Weight Sensors
*/
/* Wiring:
 * Arduino 5V -> RB 5VIN, Arduino GND -> RB GND, Arduino GPIO 4 -> RB ON/OFF, Arduino TX3 (GPIO 14) -> RB TX, Arduino RX3 (GPIO 15) -> RB RX, Weight Sensors -> A0-A3, 3.3V -> A4, 5V/GND to 5V/GND on weight sensors.
 * NOTE: Read to Read and write to write
*/  
// For more details on any of these requirements/setup instructions/Wiring Diagram see Supplemental

//**********************************************************************************************************************************************************//
//Include libraries
#include <IridiumSBD.h> //Library used to communicate with RockBLOCK Module

//Station Identifiers
const uint8_t STATION_NUMBER = 1;
const char    ROCKBLOCK_NUMBER[] = "300234067431270";

//Debugging
#define DIAGNOSTICS false // Change this to see diagnostics (unimplemented)

// Rockblock error handling
int signalQuality = -1; // used for testing signal strength
int err;                // Used for status of built in functions of library

// Declare the Rockblock with an IridiumSBD object (Initializing Satellite communication with on/off pin and serial pins)
#define IridiumSerial Serial3  // Rx15 and Tx 14 -> NOTE: If you aren't using a MEGA you will probably have to change this.
const int SLEEP_PIN = 4;       //This pin is used to turn satellite module on/off
IridiumSBD modem(IridiumSerial, SLEEP_PIN);

// Define analog pins 
const int Sensor_0 = A0; //Weight sensors 
const int Sensor_1 = A1;  
const int Sensor_2 = A2;
const int Sensor_ref = A8; //This is just the 3.3V wired to the ADC so we have a reference/control to make sure that the ADC is working as expected

// Calibration Curve
const float FC2231_ADC_TO_LBS_SLOPE = 0.37;        //slope for ADC to lbs calibration curve
const float FC2231_ADC_TO_LBS_INTCPT = -41.5;      //y-intercept for ADC to lbs calibration curve

const float BARREL_WGHT = 36.4;                    //weight of the water barrel and the shelving unit (in lbs)

//initialize the array for storing satellite transmission data
const size_t data_array_size = 48;                 //size of the transmission data array
uint8_t data[data_array_size];

// Alarms set and reset values
const float LOW_WGHT_TRIG = 25.02; //low weight trigger (in lbs)
const float LOW_WGHT_RST = 110;    //reset for the low weight alarm (in lbs)
int alarms_triggered = 0;          //alarms are unset on power up

//Used as state indicator to do test send when first powered on/rebooted
int init_const = 0;

//Initialize Arrays
int data_avg[5];
float data_weight[5];
//**********************************************************************************************************************************************************//

//**********************************************************************************************************************************************************//
void writingData(uint8_t *data, int index) {
  // This function reads each weight sensor and then updates the data array with the values.
  /* INPUTS
   * Data: must be char array and be 5 length.
   * Index: must be integer
   * 
   * OUTPUTS
   * NONE
  */
   
  /* OPERATION
   *  This function reads each weight sensor and ref votlage 800 times, then takes the average of each (called sampled_n). 
   *  Next, we output these values to the data array, positioning them in the array based on the index variable. If you pass in an index of 5, then the function puts
   *  sampled_0 at data[5], sampled_1 at data[6], etc. 
   *  NOTE: because C++ can't return an array, we simply change the values of the input array. 
   *  NOTE: This array must have already been initialized before calling this function.
   *  
  */
  //Accumulators used to hold sums for multisampling (unsigned 32 bit integers because theoretically they could be as large as 100,000 each).
  uint32_t sum_0 = 0; 
  uint32_t sum_1 = 0;
  uint32_t sum_2 = 0;
  uint32_t sum_ref = 0;
  char tmp = 0;
  
  //Multisampling each weight sensor and reference
  for(int i=0;i<800;i++) {
    int analog_0 = analogRead(Sensor_0);
    sum_0 += analog_0;
    int analog_1 = analogRead(Sensor_1);
    sum_1 += analog_1;
    int analog_2 = analogRead(Sensor_2);
    sum_2 += analog_2;
    int analog_ref = analogRead(Sensor_ref);
    sum_ref += analog_ref;
  }

  //Average sample.
  uint32_t sampled_0   = sum_0/800;
  uint32_t sampled_1   = sum_1/800;
  uint32_t sampled_2   = sum_2/800;
  uint32_t sampled_ref = sum_ref/800;
  
  tmp = map(sampled_0,0,1023,0,255);
  data[index] = tmp;
  tmp = map(sampled_1,0,1023,0,255);
  data[index+1] = tmp;
  tmp = map(sampled_2,0,1023,0,255);
  data[index+2] = tmp;
  tmp = map(sampled_ref,0,1023,0,255);
  data[index+3] = tmp;
  float tmp2 = (((sampled_0+sampled_1+sampled_2)/3)*FC2231_ADC_TO_LBS_SLOPE+FC2231_ADC_TO_LBS_INTCPT-BARREL_WGHT);
  
  data[index+4] = safeChar(tmp2);
}
//**********************************************************************************************************************************************************//

//**********************************************************************************************************************************************************//
//Same as Above function but returns an array of averages (this is really only used for debugging/calibrating)
void readingDataAvg(int (& data_avg) [5], int index) {
  //Constants used to hold sums for multisampling
  // These are declared as unsigned 32 bit integers because theoretically they could be as large as 100,000 each.
  // Additionally, it is impossible for the ADC to output a negative number
  uint32_t sum_0 = 0; 
  uint32_t sum_1 = 0;
  uint32_t sum_2 = 0;

  //Multisampling each weight sensor and reference
  for(int i=0;i<800;i++) {
    int analog_0 = analogRead(Sensor_0);
    sum_0 += analog_0;
    int analog_1 = analogRead(Sensor_1);
    sum_1 += analog_1;
    int analog_2 = analogRead(Sensor_2);
    sum_2 += analog_2;
  }
  uint32_t sampled_0 = sum_0/800;
  uint32_t sampled_1 = sum_1/800;
  uint32_t sampled_2 = sum_2/800;
  uint32_t sampled_avg = (sampled_0+sampled_1+sampled_2)/3;
  data_avg[index] = sampled_avg;
} 

//Same as Above function but returns an array of weights instead of raw values (this is really only used for debugging/calibrating)
void readingDataWeight(float (& data_weight) [5], int index) {
  //Constants used to hold sums for multisampling
  // These are declared ass unsigned 32 bit integers because theoretically they could be as large as 100,000 each.
  // Additionally, it is impossible for the ADC to output a negative number (hopefully)
  uint32_t sum_0 = 0; 
  uint32_t sum_1 = 0;
  uint32_t sum_2 = 0;

  //Multisampling each weight sensor and reference
  for(int i=0;i<800;i++) {
    int analog_0 = analogRead(Sensor_0);
    sum_0 += analog_0;
    int analog_1 = analogRead(Sensor_1);
    sum_1 += analog_1;
    int analog_2 = analogRead(Sensor_2);
    sum_2 += analog_2;
  }
  uint32_t sampled_0   = sum_0/800;
  uint32_t sampled_1   = sum_1/800;
  uint32_t sampled_2   = sum_2/800;
  float sampled_weight = ((((sampled_0+sampled_1+sampled_2)/3)*FC2231_ADC_TO_LBS_SLOPE+FC2231_ADC_TO_LBS_INTCPT-BARREL_WGHT));
  data_weight[index]   = sampled_weight;
} 
//*************************************************************************************************************************************************************//

//*************************************************************************************************************************************************************//
int sendingData(uint8_t *data_ptr) {
  // This function is responsible for sending the data using the RockBLOCK module.
  /* INPUTS
   * Data Array: Must be int array of 42 length
   */
  /* OUTPUTS
   * Error: Integer representing the err outputted from the modem.sendSBDText function. This indicator allows us to keep trying to send data if it fails the first time.
   */
  /* OPERATION
   * This function has a few key components: Initialization, Signal Quality, and Sending Data, these are separated by -------
   * Initialization: "Wakes up the Modem", prints various errors/debugging to Serial
   * Signal Quality: Tests the signal quality which can differ based on the position of the satellites or heavy cloud cover/fog. Alost prints debugging info.
   * Sending Data: First converts the int array into a string, adding extra zeros so that each sensor reading is represented by three digits. The reason we do this is so we can then cast this string into a char array that is accepted by the sendSBDText function. This is pretty convoluted but we were working on short time budget.
   * Next, we create a pointer to the beginning of our char array (This is the required input to the sendSBDText function).
   * Then we Call the function, and have some options for debugging info.
   * For more info on the SBDsendText function see the Readme which has some helpful documents.
  */
  //--------------------------------Initalize the Rockblock--------------------------------------//
  // Initialize the modem to get ready for sending/receiving data.
  Serial.println("Waking up module");
  err = modem.begin();
  //Check to make sure the module woke up.  
  if (err != ISBD_SUCCESS){      
    Serial.print("Begin failed: error ");          
    Serial.println(err);
    //Check to see if there is even a Rockblock connected to the controller.
    if (err == ISBD_NO_MODEM_DETECTED){
      Serial.println("No modem detected: check wiring.");
    } 
  }
  else if(err == ISBD_SUCCESS){
    Serial.println("Modem.begin success");
  }
  delay(500);

  //Get signal quality and print it
  err = modem.getSignalQuality(signalQuality);
  delay(5000);
  //Check to see if the controller was able to get the signal quality.
  if (err != ISBD_SUCCESS){
    Serial.print("SignalQuality failed: error ");
    Serial.println(err);
    return err;
  }
  Serial.print("On a scale of 0 to 5, signal quality is currently ");
  Serial.print(signalQuality);
  Serial.println(".");
  //-----------------------------------Sending the Data------------------------------------------//
  Serial.println("Waiting 50 seconds for capacitor to charge");
  delay (50000);
  Serial.println("Attempting to send data...");

  // NOTE: A credit is spent for every 50 bytes of data (rounded up to the nearest 50) sent using the modem.sendSBDBinary function. (i.e 1-50 bytes will cost 1 credit, 51-100 will cost 2 credits, etc.)
  // Finally, we call the sendSBDBinary function with the input being our pointer to the data array.
  Serial.print("Err Before: ");
  Serial.println(err);
  err = modem.sendSBDBinary(data_ptr, data_array_size);
  err = ISBD_SUCCESS;
  Serial.print("Err After: ");
  Serial.println(err);   
  // Different Debugging info
  if (err != ISBD_SUCCESS) {
    Serial.print("tried sending didnt work : ");
    if (err == ISBD_SENDRECEIVE_TIMEOUT) {
      Serial.println("Try again with a better view of the sky.");
    } else {
      Serial.print("Error Code: ");
      Serial.println(err);
    }
  } else if (err == ISBD_SUCCESS) {
    Serial.println("Data Sent");
  }
  return err;
}
//*************************************************************************************************************************************************************//

//*************************************************************************************************************************************************************//
char safeChar(float tmp) {
  if (tmp < 0) {
    tmp = 0;    
  } else if (tmp > 255) {
    tmp = 255;
  }
  return char(tmp);
}
//*************************************************************************************************************************************************************//

//*************************************************************************************************************************************************************//  
// These can be used for some extra debugging/diagnostics
// Both functions are REQUIRED in the code in order for the library to be utilized, even if they aren't used directly.
void ISBDConsoleCallback(IridiumSBD *device, char c) {
  #if DIAGNOSTICS
    Serial.write(c);
  #endif
}

void ISBDDiagsCallback(IridiumSBD *device, char c) {
  #if DIAGNOSTICS
    Serial.write(c);
  #endif
}
//*************************************************************************************************************************************************************// 

//*************************************************************************************************************************************************************//
void setup(){
  // Start the console serial port
  Serial.begin(115200);
  while (!Serial); //wait for port to start up
  IridiumSerial.begin(19200);    // Start the serial port connected to the satellite modem
  data[0] = STATION_NUMBER;      //First Byte of array is the station #
  data[1] = 0;                   //Second Byte of array is the alarm. 
  for (int i = 2; i < 47; i++) { //initialize data array
    data[i] = 0;
  }
}
//*************************************************************************************************************************************************************//

//*************************************************************************************************************************************************************//
// This is the main loop that runs on repeat
void loop() {    
  uint8_t *data_ptr = &data[0]; //define pointer to the array
  //This loop is meant to run when first powered on/rebooted. 
  if(init_const == 0) {
    for (int i=2;i<42;i+=5) { //fill data array
      writingData(data_ptr,i);
      delay(100);
    }
    
    for(int j =0;j<48;j++) { //print the data array
      Serial.print(data[j]);
      Serial.print(",");
    }
    Serial.println();
    
    for(int b=0; b<5; b++) {
      readingDataAvg(data_avg,b);
      delay(100);
    }
    
    for(int j =0; j<5; j++) {  //Print the average value from the data array
      Serial.print(data_avg[j]);
      Serial.print(",");
    }
    Serial.println();
    
    for(int b=0; b<5; b++) {
      readingDataWeight(data_weight,b);
      delay(100);
    }
    
    for(int j =0; j<5; j++) { //Print the weight data
      Serial.print(data_weight[j]);
      Serial.print(",");
    }
    Serial.println();
    
    int sampled_0 = analogRead(Sensor_0); //sample each sensors
    int sampled_1 = analogRead(Sensor_1);
    int sampled_2 = analogRead(Sensor_2);
    float tmp_weight = (((sampled_0+sampled_1+sampled_2)/3)*FC2231_ADC_TO_LBS_SLOPE+FC2231_ADC_TO_LBS_INTCPT-BARREL_WGHT);
   
    if(tmp_weight < LOW_WGHT_TRIG) { //check if low weight alarm should be triggered
      data[1] = 1;
      if(tmp_weight <=-20) {
        data[1] = 2;
      }
    }
     
    data[45] = safeChar(tmp_weight);
    
    int test_error = sendingData(data_ptr); //Try Once
    delay(5000);
  
  //    while(test_error != ISBD_SUCCESS)
  //    {
  //      test_error = sendingData(data);
  //      delay(5000);
  //    }
  
    init_const = 1;
  }
  
  //Put modem to sleep after sending data
  Serial.println("Putting modem to sleep.");
  err = modem.sleep();
  if(err != ISBD_SUCCESS) {
    Serial.print("sleep failed: error ");
    Serial.println(err);
  }
  
  //Clear Data$ Alarm After Initial Send
  for(int i = 1; i <= 47; i++) { //reset data array
    data[i] = 0;
  }
  
  //This loop fills the array with data, and then once full it sends it 
  for(int i=2; i<42; i+=5) {
    writingData(data_ptr,i);
    
    //Print the data being saved into the data array after each iteration of the loop
    for(int j =0; j<48; j++) {
      Serial.print(data[j]);  
      Serial.print(",");
    }
    Serial.println();
    delay(5400000); //Wait 90 minutes, this causes data to be sent approximately once every 12 hours as the loop iterates 8 times
    //delay(60000); //Wait 60s (for testing)
  } 
  
  //Fill the last index with the current weight
    int sampled_0 = analogRead(Sensor_0);
    int sampled_1 = analogRead(Sensor_1);
    int sampled_2 = analogRead(Sensor_2);
    float tmp_weight = (((sampled_0+sampled_1+sampled_2)/3)*FC2231_ADC_TO_LBS_SLOPE+FC2231_ADC_TO_LBS_INTCPT-BARREL_WGHT);
    
    if(tmp_weight < LOW_WGHT_TRIG) { //check if low weight alarm should be triggered
      data[1] = 1;
      if(tmp_weight <=-20) {
        data[1] = 2;
      }
    }
     
    data[45] = safeChar(tmp_weight); //store most recent weight 
  
  for(int j =0;j<48;j++) { //print data to be transmitted
    Serial.print(data[j]);  
    Serial.print(",");
  }
  Serial.println();
  
  //This sends the data, saving the err from the modem.sendSBDBinary function as the output
  //If the function outputs anything other than a success it tries to send the data again
  int error = sendingData(data_ptr);
  delay(5000);
  while(error != ISBD_SUCCESS) { //keep trying to transmit via satellite (NO TIMEOUT)
    error = sendingData(data_ptr);
  delay(5000);
  }
  
  //Put modem to sleep after sending data
  Serial.println("Putting modem to sleep.");
  err = modem.sleep();
  if (err != ISBD_SUCCESS) {
    Serial.print("sleep failed: error ");
    Serial.println(err);
  }
}
//*************************************************************************************************************************************************************//

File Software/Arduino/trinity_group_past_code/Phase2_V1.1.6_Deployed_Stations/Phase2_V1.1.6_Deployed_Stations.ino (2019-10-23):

//Phase 2 V1.1.3 Deloyed Stations Code for Trinity University Water Stations Project
//Authors: Sean Farrell, Caroline Kutach, Nathan Richter, Brady Burns, Brian Guenther, and Zach
//Last Update:
//--5/30/19
/* Updates to the satellite transmission array 
   * Underflow and overflow checking and handling
   * Set up unique alarms for low weight, high weight and barrel removed
*/
//--5/15/19: 
/* This version ws transitioned from V1.1.4 to V1.1.5. In this version the Satellite modem tries to send continuously in main loop
   * Also reduced the alarms to only trigger based on the weight sensor readings. I also changed it to send data twice a day at 7:00 am (7) 
   * and 6:00 pm (18). This was changed from just sending at 6:00am because we found that we could not transmit at this time with old tranmission algorithm.
*/     
//--3/21/19
/* Requirements:
   *Irridium SBD Library installed, Version of Arduino must be 1.6.21, Arduino MEGA, RockBLOCK V2.c, 4 Weight Sensors, 5 Temperature and Humidity Sensor
  
   *Wiring:
   *Arduino 5V -> RB 5VIN, Arduino GND -> RB GND, Arduino GPIO 4 -> RB ON/OFF, Arduino TX3 (GPIO 14) -> RB TX, Arduino RX3 (GPIO 15) -> RB RX,
   *Weight Sensors -> A0-A3, 3.3V -> A4, 5V/GND to 5V/GND on weight sensors.
   *SD card -> MOSI = 51, SS = 53, MISO = 50, CLK = 52, GND, 5V
   *Temperature/Humidity sensor (DHT11)  -> (-) = GND, (+) = 5V, (S) = 49
   *NOTE: Read to Read and write to write (This is weird)

   *Purpose:
   *This code is used to read the water weight at each of the water stations deployed by the South Texas Human
   *Rights Association and send that data via satellite to be uploaded to thier website.
   *Key objectives of the code are listed below:
   *1) Read weight using Analog ports and GPS location using Satellite module
   *2) Keep track of real time using Real Time CLock (RTC) module
   *3) Send weight data at standard intervals (currently set to 7:00am and 7:00pm)
   *4) Read station parameters (battery voltage, current)
   *5) Save station parameters to a removable SD card (acting like EEPROM)
*/
//Station Identifiers
const uint8_t STATION_NUMBER = 6;
const char    ROCKBLOCK_NUMBER[] = "300234067929930";

//Include Libraries
#include <IridiumSBD.h>                   //Satellite Module
#include <SoftwareSerial.h>               //Satellite Module
//#include "HX711.h"                        //Weight Sensors
#include <Wire.h>                         //RTC Module (I2C commuication)
#include <RTClib.h>                       //RTC Module
#include <SD.h>                           //SD card Module (SPI communication)
#include <SPI.h>                          //Library for SPI communication
#include <dht.h>                          //Temperature and humidity sensor library

//*********************************************************************************************************************************************************//
/*
   Section of code is designated for Defintions, Constants, and Variable Declarations
   It is ordered 1) Rockblock (Satellite module), 2) Sensors, 3) Real Time Clock (RTC), 4) SD Card Module
*/
// --------ROCKBLOCK SECTION:
// Definitions used for controlling RockBLOCK
#define IridiumSerial Serial3       // Rx15 and Tx 14 -> NOTE: If you aren't using a MEGA you will probably have to change this.
#define DIAGNOSTICS false           // Change this to see diagnostics
const int SLEEP_PIN = 4;            // This pin is used to turn satellite module on/off

// Initializing Debugging Variables
int signalQuality = -1;             // Used for testing signal strength
int err;                            // Used for status of built in functions of library
int initialized = 1;                // Used during boot to send water station location and water amount to website

//Initializing/Clearing Array that holds analog values
const size_t data_array_size = 48;
uint8_t data[data_array_size];
int sample_pos = 0;                 //location within the character array

// Declare the IridiumSBD object (Initializing Satellite communication with on/off pin and serial pins)
IridiumSBD modem(IridiumSerial, SLEEP_PIN);

//variables used for improved satellite transmission method
int long current_time = 0;          //gives back current time in seconds from 1/1/1970
int long send_time = 0;             //holds the last time it tried to end data 
boolean sat_signalerr_flag = false; //set when signal quality is < 3 during transmission
int sat_send_attempt = 0;           //records how many times the function has tried sending satellite data

//--------SENSORS SECTION:
const int BATTERY_MONITOR = 58;     //battery voltage monitor (analog) A4
const int PANEL_CURRENT = 59;       //solar panel current monitor (analog) A5
float WEIGHT_SENSOR1 = A1;          // Analog weight sensors
float WEIGHT_SENSOR2 = A2;
float WEIGHT_SENSOR3 = A3;
//#define HX711_DT  22                //HX711 load cell amplifier
//#define HX711_CLK  23

//Constants for HX711 weight amplfier or FC2231 load cells
//const int communication_period = 1800;          //Period at which communications triggers
const int scale_calibration_factor = -9437;       //This value is obtained using the SparkFun_HX711_Calibration sketch
const float FC2231_ADC_TO_LBS_SLOPE = 0.37;       //slope for ADC to lbs calibration curve
const float FC2231_ADC_TO_LBS_INTCPT = -41.5;     //y-intercept for ADC to lbs calibration curve

const float WGHT_DIFF_TRIG = 0.2;                 //weight difference to trigger weight update

//Constants for ACS723 current Sensor
const float I_SNSR_ADC_TO_A_SLOPE = 12.299;       //slope for ADC to amps calibration curve for ACS723 current sensor
const float I_SNSR_ADC_TO_A_INTCPT = -6290;       //y-intercept for ADC to amps calibration curve for ACS723 current sensor

//Constants for resistive voltage Sensor
const float V_SNSR_ADC_TO_V_SLOPE = 0.0131;       //slope for ADC to volts calibration curve for resistive battery monitor
const float V_SNSR_ADC_TO_V_INTCPT = 0.047;       //y-intercept for ADC to volts calibration curve
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

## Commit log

2019-11-07 Adding proper project managment documents
    [BOM_updating_phase1_stations.xlsx]
2020-02-21 Version 2 of Network Control using MySQL
    [Example.csv, Satellite_Transmission_Guide.xlsx, Water_Station_Data.xlsx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]
